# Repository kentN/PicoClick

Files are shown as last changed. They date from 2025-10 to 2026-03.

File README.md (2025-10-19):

# PicoClick
raspberry pi pico berakout PCB for prototyping MICROE Click boards

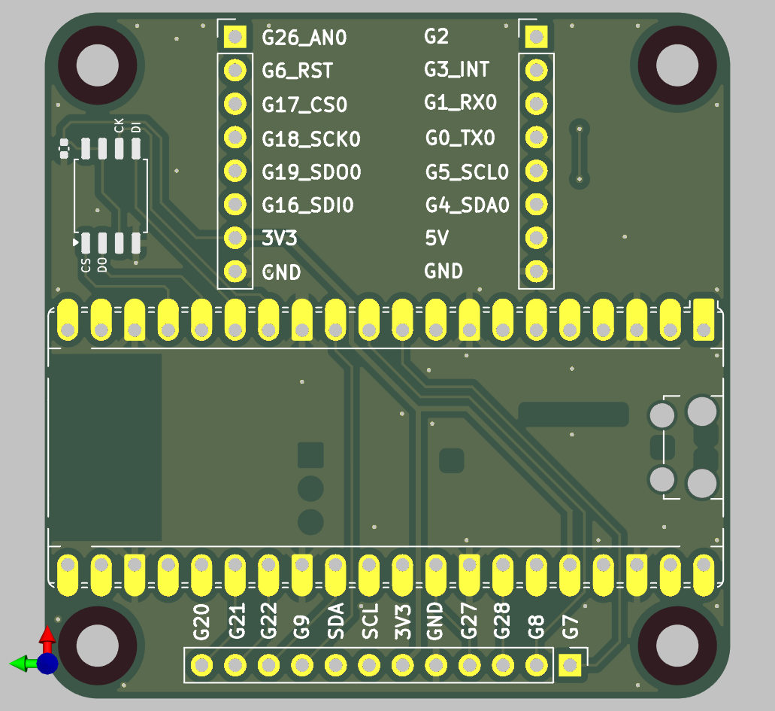
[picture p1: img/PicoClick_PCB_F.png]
PicoClick PCB Front View


---
Features

- Raspberry pi pico Header

- 10pin x2 Click boards formfacter pinsockets

- additional 12pin x1 pinsocket can mount tiny I2C Display directly

- SO8W patturn for SPI ROM on SPI1 bus (See PicoClick_sch.pdf) 

- KiCad 9.0 project

1st batch config
- Rasoberry pi pico2
- SPI ROM: SST26VF064B
https://ww1.microchip.com/downloads/en/DeviceDoc/20005119G.pdf

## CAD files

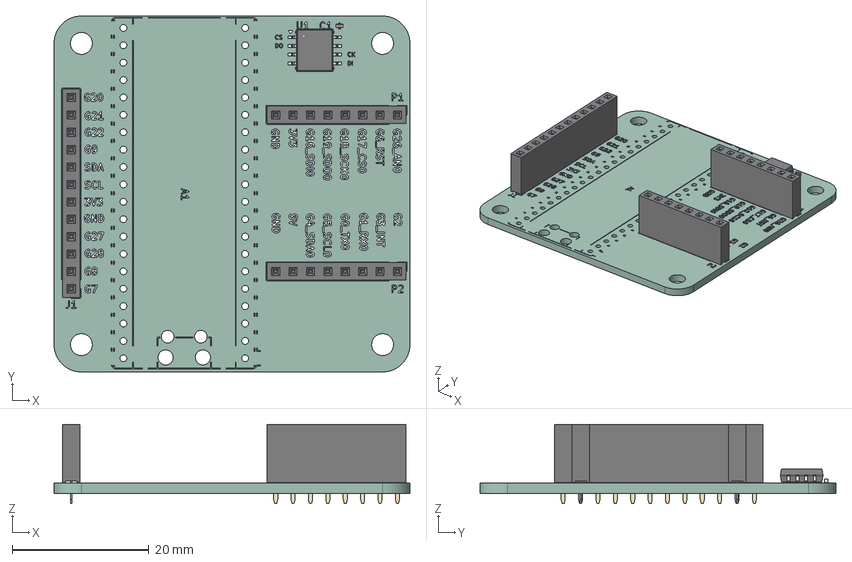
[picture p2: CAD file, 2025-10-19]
3D/PicoClick.step
52.0 x 52.0 x 11.6 mm
PinSocket_1x12_P2.54mm_Vertical
PinSocket_1x08_P2.54mm_Vertical x 2
C_0402_1005Metric
SOIC-8_5.3x6.2mm_P1.27mm
PicoClick_silkscreen
PicoClick_PCB

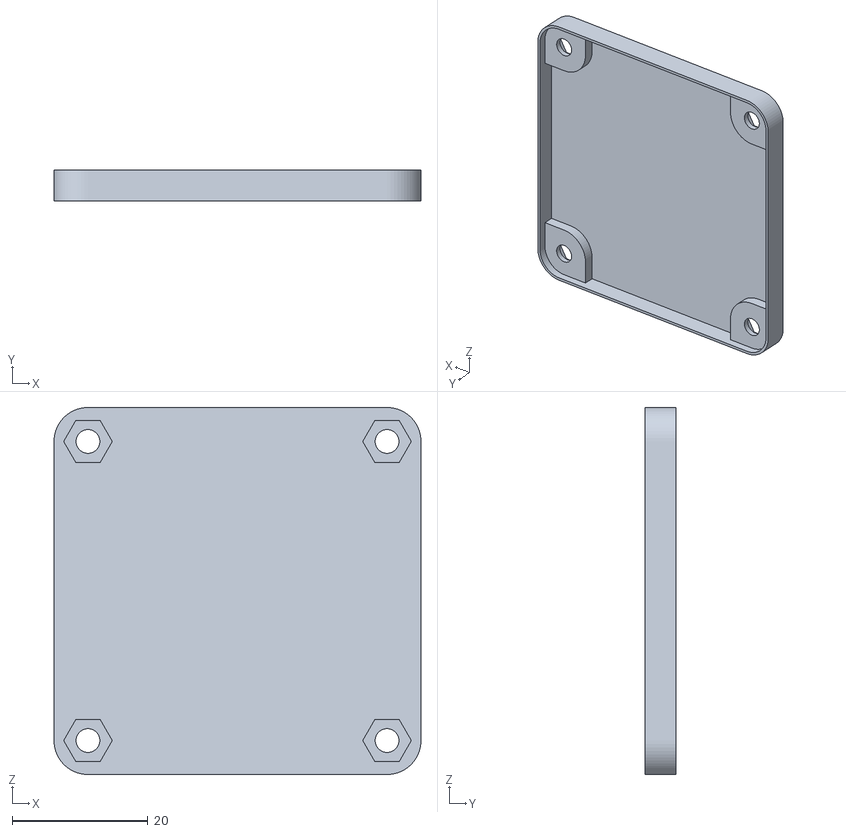
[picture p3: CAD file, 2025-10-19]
3D/PicoClick_bottom_plate.stl
54.0 x 4.50 x 54.0

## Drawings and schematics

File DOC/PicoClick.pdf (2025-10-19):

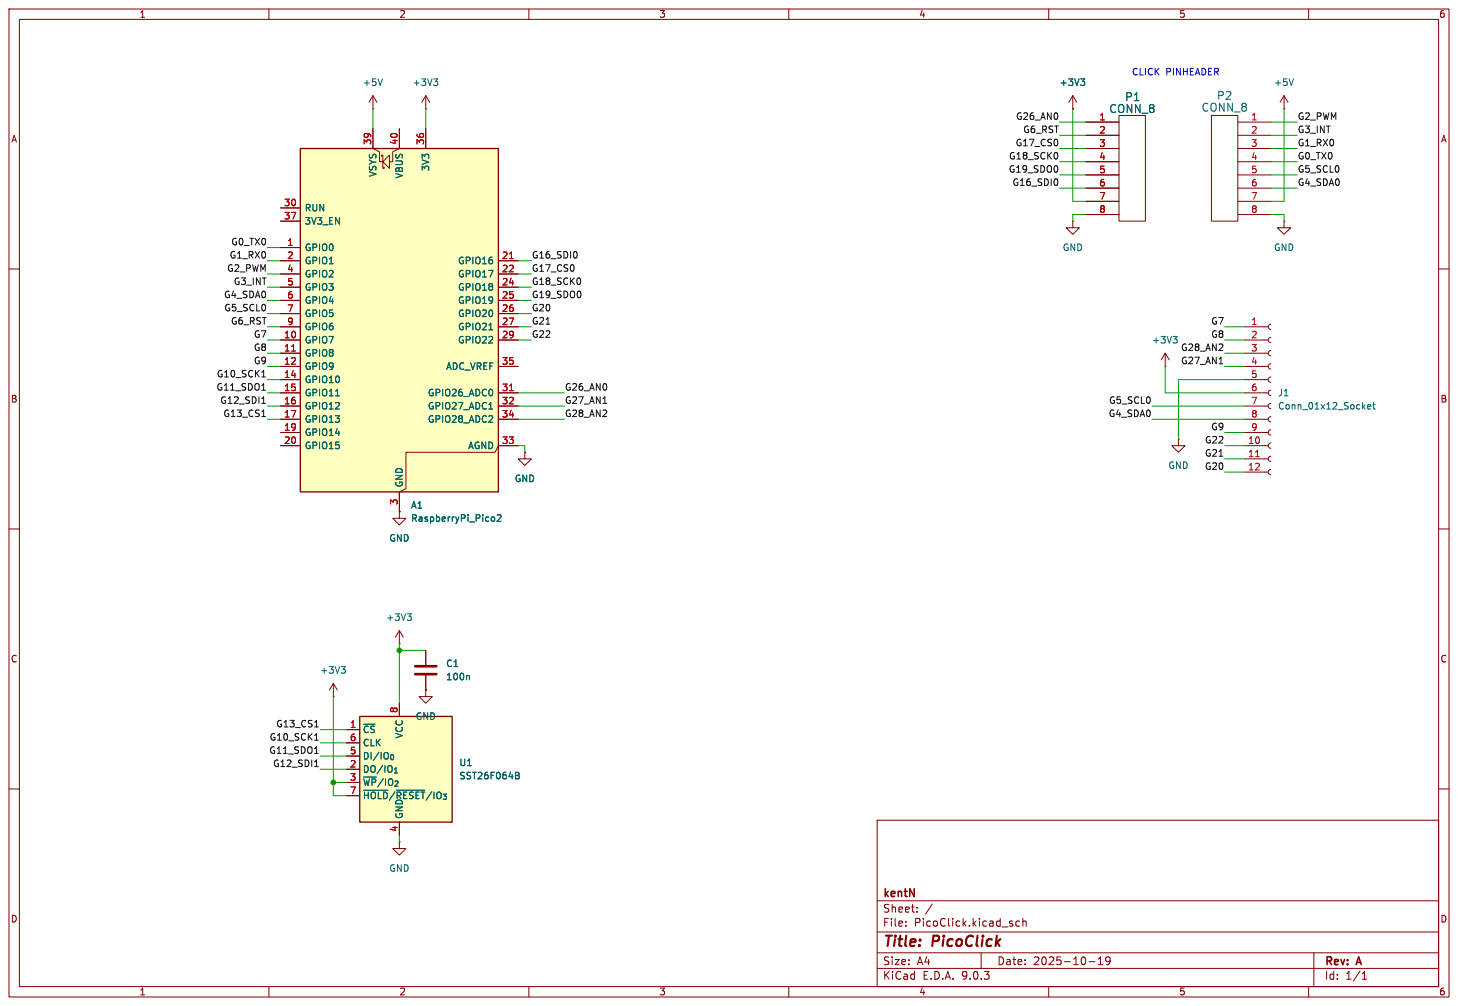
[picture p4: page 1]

File: PicoClick.kicad_sch Sheet: / kentN

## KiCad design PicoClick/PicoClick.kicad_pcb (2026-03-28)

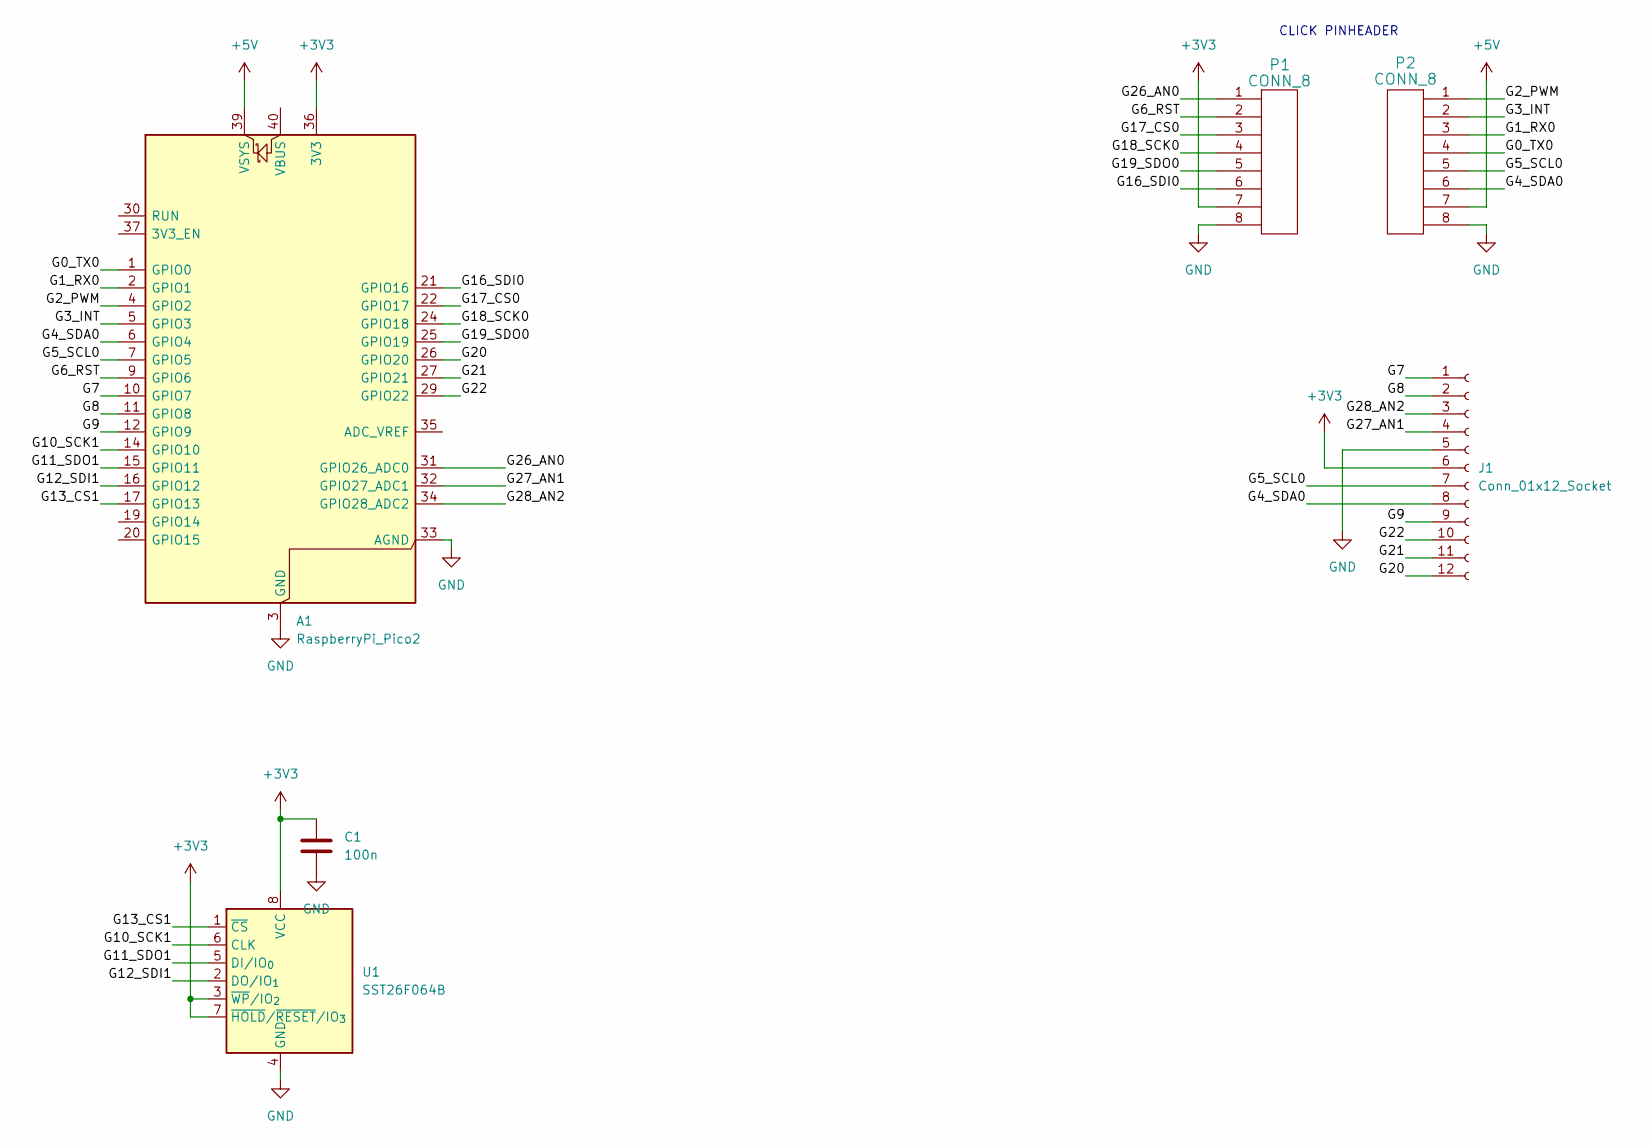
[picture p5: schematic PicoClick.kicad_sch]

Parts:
A1: RaspberryPi_Pico2; RaspberryPi_Pico_Common_Unspecified
C1: 100n; C_0402_1005Metric
J1: Conn_01x12_Socket; PinHeader_1x12_P2.54mm_Vertical
P1, P2: CONN_8; PinHeader_1x08_P2.54mm_Vertical
U1: SST26F064B; SOIC-8_5.3x5.3mm_P1.27mm

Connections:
+3V3: A1.36 (3V3), C1.1, J1.6, P1.7, U1.3 (~WP/IO_{2}), U1.7 (~HOLD/~RESET/IO_{3}), U1.8 (VCC)
+5V: A1.39 (VSYS), P2.7
/G0_TX0: A1.1 (GPIO0), P2.4
/G1_RX0: A1.2 (GPIO1), P2.3
/G2_PWM: A1.4 (GPIO2), P2.1
/G3_INT: A1.5 (GPIO3), P2.2
/G4_SDA0: A1.6 (GPIO4), J1.8, P2.6
/G5_SCL0: A1.7 (GPIO5), J1.7, P2.5
/G6_RST: A1.9 (GPIO6), P1.2
/G7: A1.10 (GPIO7), J1.1
/G8: A1.11 (GPIO8), J1.2
/G9: A1.12 (GPIO9), J1.9
/G10_SCK1: A1.14 (GPIO10), U1.6 (CLK)
/G11_SDO1: A1.15 (GPIO11), U1.5 (DI/IO_{0})
/G12_SDI1: A1.16 (GPIO12), U1.2 (DO/IO_{1})
/G13_CS1: A1.17 (GPIO13), U1.1 (~CS)
/G16_SDI0: A1.21 (GPIO16), P1.6
/G17_CS0: A1.22 (GPIO17), P1.3
/G18_SCK0: A1.24 (GPIO18), P1.4
/G19_SDO0: A1.25 (GPIO19), P1.5
/G20: A1.26 (GPIO20), J1.12
/G21: A1.27 (GPIO21), J1.11
/G22: A1.29 (GPIO22), J1.10
/G26_AN0: A1.31 (GPIO26_ADC0), P1.1
/G27_AN1: A1.32 (GPIO27_ADC1), J1.4
/G28_AN2: A1.34 (GPIO28_ADC2), J1.3
GND: A1.3 (GND), A1.8 (GND), A1.13 (GND), A1.18 (GND), A1.23 (GND), A1.28 (GND), A1.33 (AGND), A1.38 (GND), C1.2, J1.5, P1.8, P2.8, U1.4 (GND)

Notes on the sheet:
CLICK PINHEADER

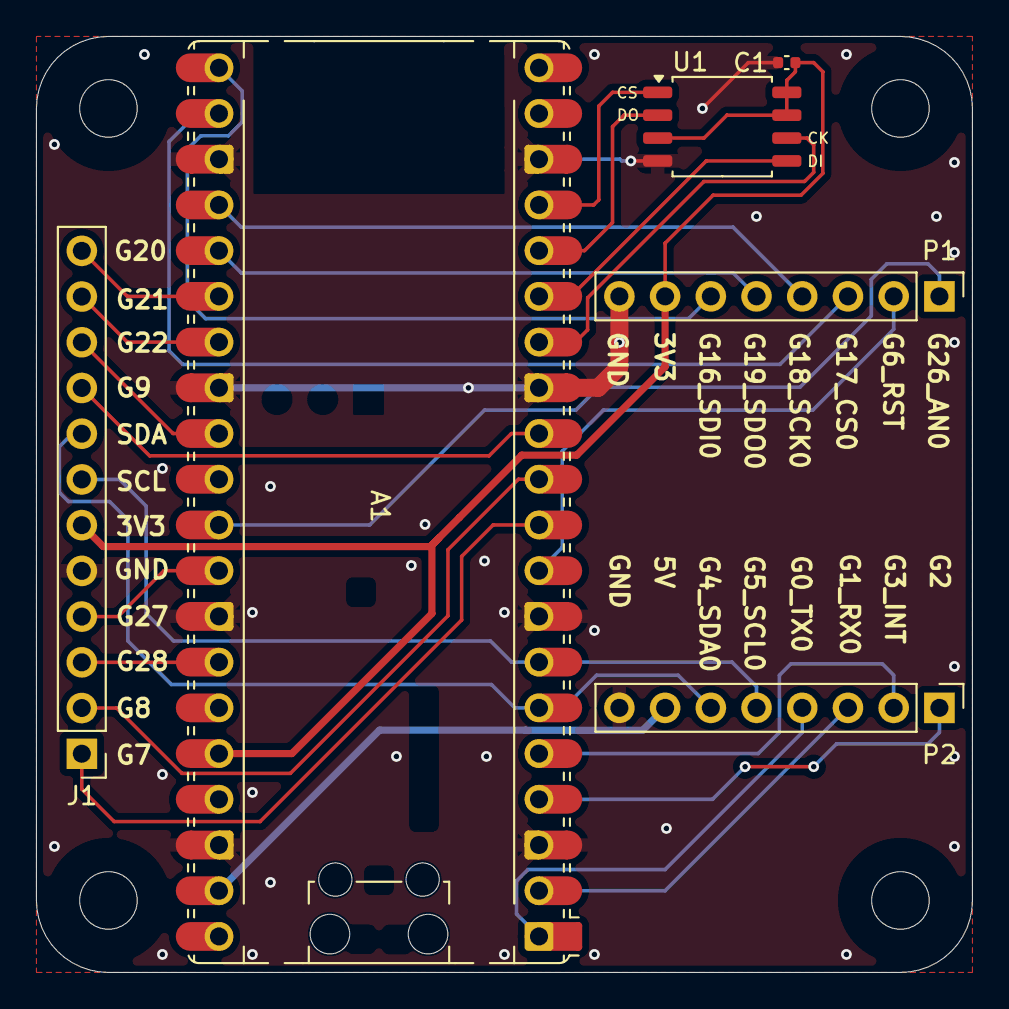
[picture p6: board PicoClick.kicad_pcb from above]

Board: 2 copper layers, 52.0 x 52.0 mm, 6 parts (0 on the bottom side), 27 nets.

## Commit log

2025-10-19 Create .gitignore
    import from https://raw.githubusercontent.com/github/gitignore/refs/heads/main/KiCad.gitignore
2025-10-19 fix SPI labels
    [PicoClick.kicad_pcb, PicoClick.kicad_sch]
2025-10-19 add board image
2025-10-19 add 3Dmodel & 3DP case
    [PicoClick.kicad_pcb, PicoClick.step, PicoClick_bottom_plate.stl]
2026-03-28 update kicad version (10)
    [PicoClick.kicad_pcb, PicoClick.kicad_sch]
